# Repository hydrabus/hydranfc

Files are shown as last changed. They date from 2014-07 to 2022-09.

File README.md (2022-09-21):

HydraNFC Shield v1 and HydraNFC Antenna
========

HydraNFC hardware shield v1
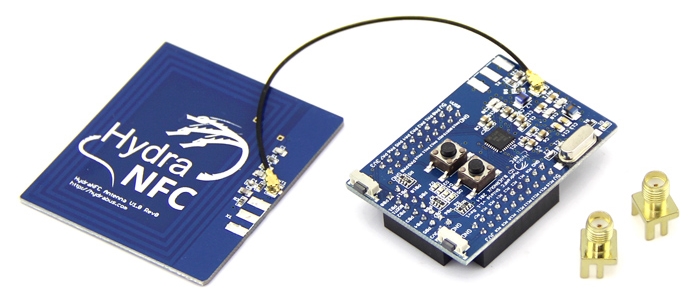
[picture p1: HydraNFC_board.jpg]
HydraNFC shield


The HydraNFC is an NFC shield hardware to sniff, read/write or emulate any 13.56MHz NFC tags for anyone interested in debugging/hacking/developing for NFC.
It has been designed to be used with HydraBus see https://github.com/hydrabus/hydrabus but can also be used with other MCU.

You can Buy HydraBus/HydraNFC Online: http://hydrabus.com/buy-online

Open source code firmware(For HydraBus), is available see
https://github.com/hydrabus/hydrafw

Wiki for HydraFW: https://github.com/hydrabus/hydrafw/wiki

Tutorial with HydraBus + HydraNFC  (using HydraFW v0.5 beta):
* Initialize GPIO & SPI to communicate with TRF7970A/HydraNFC
* Initialize & read ISO15693/Vicinity Tag
* Initialize & read ISO14443A/Mifare Tag
* Use TRF7970A commands (SLOS743K – August 2011 – revised April 2014)
* For more details see 
https://github.com/hydrabus/hydrafw/wiki/HydraFW-HydraNFC-v1-guide
https://github.com/hydrabus/hydrafw/wiki/HydraFW-HydraNFC-v1.x-TRF7970A-Tutorial

Tutorial to use HydraNFC and understand how work the NFC chipset (TRF7970A) with BusPirate or any other hardware with SPI:
* See http://bvernoux.blogspot.fr/2012/01/nfc-ti-trf7970a-breakout-board-v10-for.html

For more details on the hardware see also http://hydrabus.com/hydranfc-1-0-specifications

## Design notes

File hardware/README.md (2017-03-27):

HydraNFC Hardware
========

This directory contains HydraNFC Hardware: 
Schematic, Board for CadSoft Eagle 6.x (free version works too)
Documentations HydraNFC TRF7970A chipset Modes & Pin Out.

Licenses:
* HydraNFC_1_1_Rev1 and HydraNFC_Antenna_1_0_Rev0: Hardware license [CC BY-NC 4.0](https://creativecommons.org/licenses/by-nc/4.0/) (for commercial license contact info@hydrabus.com)

You can buy online HydraBus/HydraNFC: http://hydrabus.com/buy-online

For more details on the hardware see also http://hydrabus.com/hydranfc-1-0-specifications/

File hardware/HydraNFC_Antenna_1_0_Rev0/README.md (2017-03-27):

HydraNFC Antenna Schematic and Board CadSoft Eagle 6.x
========

This directory contains HydraNFC Antenna Schematic and Board for CadSoft Eagle 6.x

HydraNFC Antenna: Hardware license [CC BY-NC 4.0](https://creativecommons.org/licenses/by-nc/4.0/) (for commercial license contact info@hydrabus.com)

For more details on the hardware see also http://hydrabus.com/?page_id=30

HydraNFC Antenna PCB Top
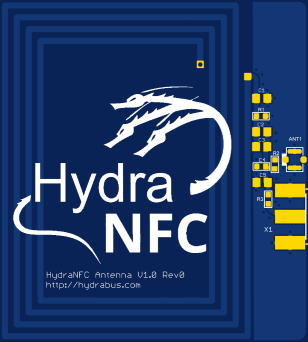
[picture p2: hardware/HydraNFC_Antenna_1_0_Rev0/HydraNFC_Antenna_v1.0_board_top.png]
HydraNFC Antenna PCB Top


HydraNFC Antenna PCB Bottom
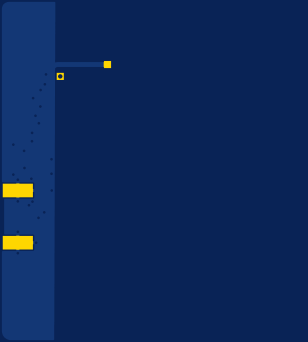
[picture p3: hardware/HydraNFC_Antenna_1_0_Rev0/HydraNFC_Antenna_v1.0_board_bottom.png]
HydraNFC Antenna PCB Bottom


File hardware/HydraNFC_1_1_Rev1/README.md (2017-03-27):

HydraNFC Shield Schematic and Board CadSoft Eagle 6.x
========

This directory contains HydraNFC shield Schematic and Board for CadSoft Eagle 6.x

HydraNFC shield: Hardware license [CC BY-NC 4.0](https://creativecommons.org/licenses/by-nc/4.0/) (for commercial license contact info@hydrabus.com)

For more details on the hardware see also http://hydrabus.com/?page_id=30

HydraNFC shield PCB Top
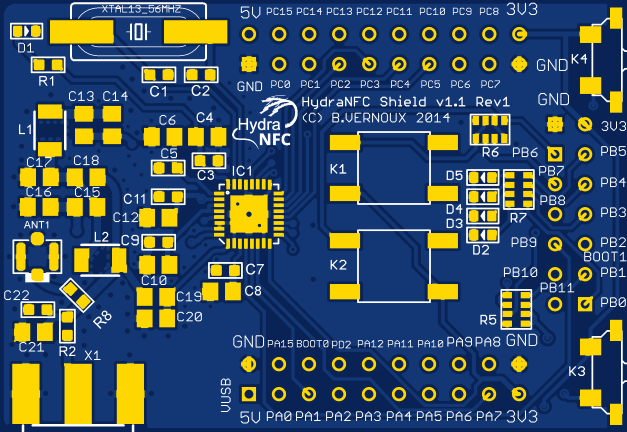
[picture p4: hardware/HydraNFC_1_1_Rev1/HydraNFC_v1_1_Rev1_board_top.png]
HydraNFC shield PCB Top


HydraNFC shield PCB Bottom
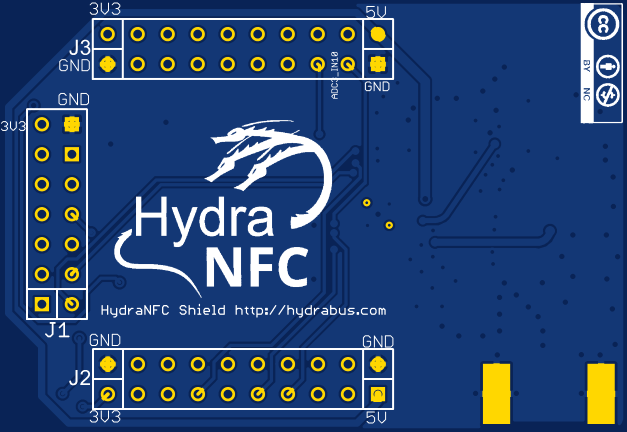
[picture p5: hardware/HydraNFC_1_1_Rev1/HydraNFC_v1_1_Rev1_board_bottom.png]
HydraNFC shield PCB Bottom


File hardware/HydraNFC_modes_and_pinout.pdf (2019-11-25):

Hydra NFC Pin | TRF7970A Pin | HydraBus Mode SPI With SS
PC0 | IO2 | +3V3 or TX SDM (Data En) out
PC1 | IO4_CS | SPI2 CS Master out
PC2 | IO6_MISO | SPI2 MISO Master or RX DM1 in
PC3 | IO7_MOSI | SPI2 MOSI Master out
PC4 | IO5 | TX SDM or RX DM1 CLK in
PC5 | IO3 | TX SDM out
PB1 | ASK_OOK | TX SDM or Direct Mode 0 out
PB10 | DATA_CLK | SPI2 CLK Master out
PB11 | EN (Chip En) | +3V3 out
PA1 | IRQ | IRQ Input in
PA2 | IO1 | +3V3 out
PA3 | IO0 | GND out
PA5 | SYS_CLK (Out) | SPI1 CLK Slave (sniffer) in
PA7 | MOD | SPI1 MOSI Slave (sniffer) in

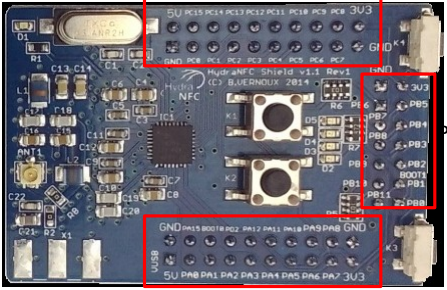
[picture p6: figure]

IO2: TX SDM Enable (TRF7970A Data Enable input)
IO3: TX SDM Data (TRF7970A Data Bit input)
IO5: TX SDM Clock or RX DM1 Clock (TRF7970A Data Clock output)
IO6: SPI MISO or RX DM1 Data (TRF7970A Data Bit output) or Direct Mode 0 (output) subcarrier signal (digitized RF envelope signal)
MOD: External data modulation input for Direct Mode 0 or 1
ASK/OOK: Selection between ASK and OOK modulation (0 = ASK, 1 = OOK) for Direct Mode 0 or 1. Can be configured as an output to provide the received analog signal output.
SYS_CLK: Options with 13.56-MHz crystal: Off, 3.39 MHz, 6.78 MHz, or 13.56 Mhz

RX DM1 = Receive Direct Mode 1 (TRF7970A receive), TX SDM = Transmit Special Direct Mode (TRF7970A transmit) TRF7970A Pin 16 is used to supply the I/O interface pins (I/O_0 to I/O_7), IRQ, SYS_CLK, and DATA_CLK pins of the reader.

PC

PA

PB

### HydraNFC Modes & Pinout

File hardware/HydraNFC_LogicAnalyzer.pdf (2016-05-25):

HydraNFC_LogicAnalyzer
LogicAnalyzer Chan | HydraNFC Pin | TRF7970A Pin | HydraBus Mode SPI With SS
0 PC3 | | IO7_MOSI | SPI2_MOSI Master out
1 PC2 | | IO6_MISO | SPI2_MISO Master or RX DM1 in
2 PB10 | | DATA_CLK | SPI2_CLK Master out
3 PC1 | | IO4_CS | SPI2_CS Master out
4 PA7 | | MOD | SPI1_MOSI Slave (sniffer) in
5 PA5 | | SYS_CLK (Out) | SPI1_CLK Slave (sniffer) in
6 PA1 | | IRQ | IRQ Input in
7 PC4 | | IO5 | TX SDM or RX DM1 CLK in
8 PC5 | | IO3 | TX SDM out
9 PB1 | | ASK_OOK | TX SDM or Direct Mode 0 out
10 PB11 | | EN (Chip En) | +3V3 out
11 PC0 | | IO2 | +3V3 or TX SDM (Data En) out
-PA2 | | IO1 | +3V3 out
-PA3 | | IO0 | GND out

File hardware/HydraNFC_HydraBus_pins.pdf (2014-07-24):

STM32F405RGT_pinNo

Pin N° | Pin Name | Pin Type | 5V pin Tolerant | Functions | AF0 | AF1 | AF2 | AF3 | AF4 | AF5 | AF6 | AF7 | AF8 | AF9 | AF10 | AF11 | AF12 | AF13 | AF14 | AF15 | Default Function HydraBus | HydraNFC TRF7970A
1 | VBAT | - | - | - | - | - | - | - | - | - | - | - | - | - | - | - | - | - | - | - | +3V3 | -
2 | PC13 | I/O | YES | EVENTOUT / RTC_AF1 | - | - | - | - | - | - | - | - | - | - | - | - | - | - | - | -
3 | PC14-OSC32_IN (PC14) | I/O | YES | EVENTOUT / OSC32_IN(4) | - | - | - | - | - | - | - | - | - | - | - | - | - | - | - | - | Optional RTC 32,768KHz
4 | PC15-OSC32_OUT (PC15) | I/O | YES | EVENTOUT / OSC32_OUT(4) | - | - | - | - | - | - | - | - | - | - | - | - | - | - | - | - | Optional RTC 32,768KHz
5 | PH0-OSC_IN (PH0) | I/O | YES | EVENTOUT / OSC_IN(4) | - | - | - | - | - | - | - | - | - | - | - | - | - | - | - | - | Quartz 8MHz | -
6 | PH1-OSC_OUT (PH1) | I/O | YES | EVENTOUT / OSC_OUT(4) | - | - | - | - | - | - | - | - | - | - | - | - | - | - | - | - | Quartz 8MHz | -
7 | NRST | I/O | - | - | - | - | - | - | - | - | - | - | - | - | - | - | - | - | - | - | Reset Button / SWD_DEBUG
8 | PC0 | I/O | YES | ADC123_IN10 | - | - | - | - | - | - | - | - | - | - | OTG_HS_ULPI_STP | - | - | - | - | EVENTOUT | | TRF7970A IO2 pin19 (Special Direct Mode TX Enable) (MCU Out set to "1" for SPI with SS)
9 | PC1 | I/O | YES | ADC123_IN11 | - | - | - | - | - | - | - | - | - | - | - | ETH_MDC | - | - | - | EVENTOUT | | TRF7970A IO4_SS pin21 (MCU SPI2 CS Master)
10 | PC2 | I/O | YES | ADC123_IN12 | - | - | - | - | - | SPI2_MISO | I2S2ext_SD | - | - | - | OTG_HS_ULPI_DIR | ETH _MII_TXD2 | - | - | - | EVENTOUT | | TRF7970A IO6_MISO SPI pin23 (MCU SPI2 MISO Master)
11 | PC3 | I/O | YES | ADC123_IN13 | - | - | - | - | - | SPI2_MOSI I2S2_SD | - | - | - | - | OTG_HS_ULPI_NXT | ETH _MII_TX_CLK | - | - | - | EVENTOUT | | TRF7970A IO7_MOSI SPI pin24 (MCU SPI2 MOSI Master)
12 | VSSA | - | - | - | - | - | - | - | - | - | - | - | - | - | - | - | - | - | - | - | - | -
13 | VDDA | - | - | - | - | - | - | - | - | - | - | - | - | - | - | - | - | - | - | - | - | -
14 | PA0-WKUP (PA0) | I/O | YES | ADC123_IN0 / WKUP(4) | - | TIM2_CH1 TIM2_ETR | TIM 5_CH1 | TIM8_ETR | - | - | - | USART2_CTS | UART4_TX | - | - | ETH_MII_CRS | - | - | - | EVENTOUT | UBTN (User Button 0) Can be disabled by removing Jumper JMP1 UBTN | HydraBus UBTN ABORT_BUTTON (MCU In)
15 | PA1 | I/O | YES | ADC123_IN1 | - | TIM2_CH2 | TIM5_CH2 | - | - | - | - | USART2_RTS | UART4_RX | - | - | ETH_MII _RX_CLK ETH_RMII__REF_ CLK | - | - | - | EVENTOUT | | TRF7970A IRQ pin13 (MCU Input IRQ_PIN)
16 | PA2 | I/O | YES | ADC123_IN2 | - | TIM2_CH3 | TIM5_CH3 | TIM9_CH1 | - | - | - | USART2_TX | - | - | - | ETH_MDIO | - | - | - | EVENTOUT | | TRF7970A IO1 pin18 (MCU Out set to "1" for SPI with SS)
17 | PA3 | I/O | YES | ADC123_IN3 | - | TIM2_CH4 | TIM5_CH4 | TIM9_CH2 | - | - | - | USART2_RX | - | - | OTG_HS_ULPI_D0 | ETH _MII_COL | - | - | - | EVENTOUT | | TRF7970A IO0 pin17 (MCU Out set to "0" for SPI with SS)
18 | VSS | - | - | - | - | - | - | - | - | - | - | - | - | - | - | - | - | - | - | - | - | -
19 | VDD | - | - | - | - | - | - | - | - | - | - | - | - | - | - | - | - | - | - | - | - | -
20 | PA4 | I/O | NO (3.3V) | ADC12_IN4 / DAC1_OUT | - | - | - | - | - | SPI1_NSS | SPI3_NSS I2S3_WS | USART2_CK | - | - | - | - | OTG_HS_SOF | DCMI_HSYNC | - | EVENTOUT | ULED (User LED 0) Can be disabled by removing Jumper JMP1 ULED
21 | PA5 | I/O | NO (3.3V) | ADC12_IN5 / DAC2_OUT | - | TIM2_CH1 TIM2_ETR | - | TIM8_CH1N | - | SPI1_SCK | - | - | - | - | OTG_HS_ULPI_CK | - | - | - | - | EVENTOUT | | TRF7970A SYS_CLK pin27 (MCU SPI1 SCK Slave) (Sniffer mode)
22 | PA6 | I/O | YES | ADC12_IN6 | - | TIM1_BKIN | TIM3_CH1 | TIM8_BKIN | - | SPI1_MISO | - | - | - | TIM13_CH1 | - | - | - | DCMI_PIXCK | - | EVENTOUT | | (MCU SPI1 MISO Not used/Not connected)
23 | PA7 | I/O | YES | ADC12_IN7 | - | TIM1_CH1N | TIM3_CH2 | TIM8_CH1N | - | SPI1_MOSI | - | - | - | TIM14_CH1 | - | ETH_MII _RX_DV ETH_RMII _CRS_DV | - | - | - | EVENTOUT | | TRF7970A MOD pin14 (IN/OUT) (MCU SPI1 MOSI Slave) (Sniffer mode)
24 | PC4 | I/O | YES | ADC12_IN14 | - | - | - | - | - | - | - | - | - | - | - | ETH_MII_RXD0 ETH_RMII_RXD0 | - | - | - | EVENTOUT | | TRF7970A IO5 pin22 (not used for SPI mode / Data clock OUT) (MCU Out set to 0 default)
25 | PC5 | I/O | YES | ADC12_IN15 | - | - | - | - | - | - | - | - | - | - | - | ETH _MII_RXD1 ETH _RMII_RXD1 | - | - | - | EVENTOUT | | TRF7970A IO3 pin20 (Special Direct Mode TX_Data) (not used for SPI mode) (MCU Out set to 0 default / NA in SPI with SS)
26 | PB0 | I/O | YES | ADC12_IN8 | - | TIM1_CH2N | TIM3_CH3 | TIM8_CH2N | - | - | - | - | - | - | OTG_HS_ULPI_D1 | ETH _MII_RXD2 | - | - | - | EVENTOUT | | LED D2 or TST_PIN (TST_ON/TST_OFF) MCU Out fastest for oscilloscope timing checks
27 | PB1 | I/O | YES | ADC12_IN9 | - | TIM1_CH3N | TIM3_CH4 | TIM8_CH3N | - | - | - | - | - | - | OTG_HS_ULPI_D2 | ETH _MII_RXD3 | - | - | - | EVENTOUT | | TRF7970A ASK_OOK pin12 (IN/OUT)
28 | PB2-BOOT1 (PB2) | I/O | YES | | - | - | - | - | - | - | - | - | - | - | - | - | - | - | - | EVENTOUT
29 | PB10 | I/O | YES | | - | TIM2_CH3 | - | - | I2C2_SCL | SPI2_SCK I2S2_CK | - | USART3_TX | - | - | OTG_HS_ULPI_D3 | ETH_ MII_RX_ER | - | - | - | EVENTOUT | | TRF7970A DATA_CLK pin26 (MCU SPI2 SCK Master)
30 | PB11 | I/O | YES | | - | TIM2_CH4 | - | - | I2C2_SDA | - | - | USART3_RX | - | - | OTG_HS_ULPI_D4 | ETH _MII_TX_EN ETH _RMII_TX_EN | - | - | - | EVENTOUT | | TRF7970A EN (Chip Enable) pin28 (MCU Out set to "1"to enable TRF7970A)
31 | VCAP_1 | - | - | - | - | - | - | - | - | - | - | - | - | - | - | - | - | - | - | - | - | -
32 | VDD | - | - | - | - | - | - | - | - | - | - | - | - | - | - | - | - | - | - | - | - | -
33 | PB12 | I/O | YES | | - | TIM1_BKIN | - | - | I2C2_SMBA | SPI2_NSS I2S2_WS | - | USART3_CK | - | CAN2_RX | OTG_HS_ULPI_D5 | ETH _MII_TXD0 ETH _RMII_TXD0 | OTG_HS_ID | - | - | EVENTOUT | USB ID (USB1 connector) | -
34 | PB13 | I/O | YES | OTG_HS_VBUS | - | TIM1_CH1N | - | - | - | SPI2_SCK I2S2_CK | - | USART3_CTS | - | CAN2_TX | OTG_HS_ULPI_D6 | ETH _MII_TXD1 ETH _RMII_TXD1 | - | - | - | EVENTOUT | Supply VUSB (USB1 connector) | -
35 | PB14 | I/O | YES | | - | TIM1_CH2N | - | TIM8_CH2N | - | SPI2_MISO | I2S2ext_SD | USART3_RTS | - | TIM12_CH1 | - | - | OTG_HS_DM | - | - | EVENTOUT | USB D-(USB1 connector) | -
36 | PB15 | I/O | YES | | RTC_50Hz | TIM1_CH3N | - | TIM8_CH3N | - | SPI2_MOSI I2S2_SD | - | - | - | TIM12_CH2 | - | - | OTG_HS_DP | - | - | EVENTOUT | USB D+ (USB1 connector) | -
37 | PC6 | I/O | YES | | - | - | TIM3_CH1 | TIM8_CH1 | - | I2S2_MCK | - | - | USART6_TX | - | - | - | SDIO_D6 | DCMI_D0 | - | EVENTOUT
38 | PC7 | I/O | YES | | - | - | TIM3_CH2 | TIM8_CH2 | | | I2S3_MCK | | USART6_RX | | | | SDIO_D7 | DCMI_D1 | | EVENTOUT
39 | PC8 | I/O | YES | | - | - | TIM3_CH3 | TIM8_CH3 | | | | | USART6_CK | | | | SDIO_D0 | DCMI_D2 | | EVENTOUT | MicroSD Card SD 4bits SDIO_D0 | -
40 | PC9 | I/O | YES | | MCO2 | - | TIM3_CH4 | TIM8_CH4 | I2C3_SDA | I2S_CKIN | | | | | | | SDIO_D1 | DCMI_D3 | | EVENTOUT | MicroSD Card SD 4bits SDIO_D1 | -
41 | PA8 | I/O | YES | | MCO1 | TIM1_CH1 | - | - | I2C3_SCL | - | - | USART1_CK | - | - | OTG_FS_SOF | - | - | - | - | EVENTOUT
42 | PA9 | I/O | YES | OTG_FS_VBUS | - | TIM1_CH2 | - | - | I2C3_SMBA | - | - | USART1_TX | - | - | | - | - | DCMI_D0 | - | EVENTOUT
43 | PA10 | I/O | YES | | - | TIM1_CH3 | - | - | | - | - | USART1_RX | - | - | OTG_FS_ID | - | - | DCMI_D1 | - | EVENTOUT
44 | PA11 | I/O | YES | | - | TIM1_CH4 | - | - | | - | - | USART1_CTS | - | CAN1_RX | OTG_FS_DM | - | - | - | - | EVENTOUT | USB D-(USB0 connector) | -
45 | PA12 | I/O | YES | | - | TIM1_ETR | - | - | - | - | - | USART1_RTS | - | CAN1_TX | OTG_FS_DP | - | - | - | - | EVENTOUT | USB D+ (USB0 connector) | -
46 | PA13 (JTMS-SWDIO) | I/O | YES | | JTMS-SWDIO | - | - | - | - | - | - | - | - | - | - | - | - | - | - | EVENTOUT | SWDIO | -
47 | VCAP_2 | - | - | - | - | - | - | - | - | - | - | - | - | - | - | - | - | - | - | - | - | -
48 | VDD | - | - | - | - | - | - | - | - | - | - | - | - | - | - | - | - | - | - | - | - | -
49 | PA14 (JTCK-SWCLK) | I/O | YES | | TCK-SWCLK | - | - | - | - | - | - | - | - | - | - | - | - | - | - | EVENTOUT | SWCLK | -
50 | PA15 (JTDI) | I/O | YES | | JTDI | TIM 2_CH1 TIM 2_ETR | - | - | - | SPI1_NSS | SPI3_NSS/ I2S3S_WS | - | - | - | - | - | - | - | - | EVENTOUT | | (MCU SPI1 NSS Slave) (Sniffer mode)
51 | PC10 | I/O | YES | | - | - | - | - | - | - | SPI3_SCK/ I2S3S_CK | USART3_TX/ | UART4_TX | - | - | - | SDIO_D2 | DCMI_D8 | - | EVENTOUT | MicroSD Card SD 4bits SDIO_D2 | -
52 | PC11 | I/O | YES | | - | - | - | - | - | I2S3ext_SD | SPI3_MISO/ | USART3_RX | UART4_RX | - | - | - | SDIO_D3 | DCMI_D4 | - | EVENTOUT | MicroSD Card SD 4bits SDIO_D3 | -
53 | PC12 | I/O | YES | | - | - | - | - | - | - | SPI3_MOSI I2S3_SD | USART3_CK | UART5_TX | - | - | - | SDIO_CK | DCMI_D9 | - | EVENTOUT | MicroSD Card SD 4bits SDIO_CK | -
54 | PD2 | I/O | YES | | - | - | TIM3_ETR | - | - | - | - | - | UART5_RX | - | - | - | SDIO_CMD | DCMI_D11 | - | EVENTOUT | MicroSD Card SD 4bits SDIO_CMD | -
55 | PB3 (JTDO/ TRACESWO) | I/O | YES | | JTDO/ TRACESWO | TIM2_CH2 | - | - | - | SPI1_SCK | SPI3_SCK I2S3_CK | - | - | - | - | - | - | - | - | EVENTOUT | | LED D3 (MCU Out)
56 | PB4 (NJTRST) | I/O | YES | | NJTRST | - | TIM3_CH1 | - | - | SPI1_MISO | SPI3_MISO | I2S3ext_SD | - | - | - | - | - | - | - | EVENTOUT | | LED D4 (MCU Out)
57 | PB5 | I/O | YES | | - | - | TIM3_CH2 | - | I2C1_SMBA | SPI1_MOSI | SPI3_MOSI I2S3_SD | - | - | CAN2_RX | OTG_HS_ULPI_D7 | ETH _PPS_OUT | - | DCMI_D10 | - | EVENTOUT | | LED D5 (MCU Out)
58 | PB6 | I/O | YES | | - | - | TIM4_CH1 | - | I2C1_SCL | - | - | USART1_TX | - | CAN2_TX | - | - | - | DCMI_D5 | - | EVENTOUT | | BUTTON K2 (MCU In)
59 | PB7 | I/O | YES | | - | - | TIM4_CH2 | - | I2C1_SDA | - | - | USART1_RX | - | - | - | - | FSMC_NL | DCMI_VSYNC | - | EVENTOUT | | BUTTON K1 (MCU In)
60 | BOOT0 | I | - | - | - | - | - | - | - | - | - | - | - | - | - | - | - | - | - | - | Default Boot from Flash (pull-down resistor 2.2Kohms) | -
61 | PB8 | I/O | YES | | - | - | TIM4_CH3 | TIM10_CH1 | I2C1_SCL | - | - | - | - | CAN1_RX | - | ETH _MII_TXD3 | SDIO_D4 | DCMI_D6 | - | EVENTOUT | | BUTTON K3 (MCU In)
62 | PB9 | I/O | YES | | - | - | TIM4_CH4 | TIM11_CH1 | I2C1_SDA | SPI2_NSS I2S2_WS | - | - | - | CAN1_TX | - | - | SDIO_D5 | DCMI_D7 | - | EVENTOUT | | BUTTON K4 (MCU In)
63 | VSS | - | - | - | - | - | - | - | - | - | - | - | - | - | - | - | - | - | - | - | - | -
64 | VDD | - | - | - | - | - | - | - | - | - | - | - | - | - | - | - | - | - | - | - | - | -

Pin 3.3V Only !! Not 5V tolerant
Default Function HydraBus
HydraBus Conf HydraNFC TRF7970A

STM32F405RGT_TRF7970A_IO

Pin N° | Pin Name | Pin Type | 5V pin Tolerant | Functions | AF0 | AF1 | AF2 | AF3 | AF4 | AF5 | AF6 | AF7 | AF8 | AF9 | AF10 | AF11 | AF12 | AF13 | AF14 | AF15 | Default Function HydraBus | HydraNFC TRF7970A
1 | VBAT | - | - | - | - | - | - | - | - | - | - | - | - | - | - | - | - | - | - | - | +3V3 | -
12 | VSSA | - | - | - | - | - | - | - | - | - | - | - | - | - | - | - | - | - | - | - | - | -
13 | VDDA | - | - | - | - | - | - | - | - | - | - | - | - | - | - | - | - | - | - | - | - | -
18 | VSS | - | - | - | - | - | - | - | - | - | - | - | - | - | - | - | - | - | - | - | - | -
19 | VDD | - | - | - | - | - | - | - | - | - | - | - | - | - | - | - | - | - | - | - | - | -
31 | VCAP_1 | - | - | - | - | - | - | - | - | - | - | - | - | - | - | - | - | - | - | - | - | -
32 | VDD | - | - | - | - | - | - | - | - | - | - | - | - | - | - | - | - | - | - | - | - | -
33 | PB12 | I/O | YES | | - | TIM1_BKIN | - | - | I2C2_SMBA | SPI2_NSS I2S2_WS | - | USART3_CK | - | CAN2_RX | OTG_HS_ULPI_D5 | ETH _MII_TXD0 ETH _RMII_TXD0 | OTG_HS_ID | - | - | EVENTOUT | USB ID (USB1 connector) | -
34 | PB13 | I/O | YES | OTG_HS_VBUS | - | TIM1_CH1N | - | - | - | SPI2_SCK I2S2_CK | - | USART3_CTS | - | CAN2_TX | OTG_HS_ULPI_D6 | ETH _MII_TXD1 ETH _RMII_TXD1 | - | - | - | EVENTOUT | Supply VUSB (USB1 connector) | -
35 | PB14 | I/O | YES | | - | TIM1_CH2N | - | TIM8_CH2N | - | SPI2_MISO | I2S2ext_SD | USART3_RTS | - | TIM12_CH1 | - | - | OTG_HS_DM | - | - | EVENTOUT | USB D-(USB1 connector) | -
36 | PB15 | I/O | YES | | RTC_50Hz | TIM1_CH3N | - | TIM8_CH3N | - | SPI2_MOSI I2S2_SD | - | - | - | TIM12_CH2 | - | - | OTG_HS_DP | - | - | EVENTOUT | USB D+ (USB1 connector) | -
39 | PC8 | I/O | YES | | - | - | TIM3_CH3 | TIM8_CH3 | | | | | USART6_CK | | | | SDIO_D0 | DCMI_D2 | | EVENTOUT | MicroSD Card SD 4bits SDIO_D0 | -
40 | PC9 | I/O | YES | | MCO2 | - | TIM3_CH4 | TIM8_CH4 | I2C3_SDA | I2S_CKIN | | | | | | | SDIO_D1 | DCMI_D3 | | EVENTOUT | MicroSD Card SD 4bits SDIO_D1 | -
44 | PA11 | I/O | YES | | - | TIM1_CH4 | - | - | | - | - | USART1_CTS | - | CAN1_RX | OTG_FS_DM | - | - | - | - | EVENTOUT | USB D-(USB0 connector) | -
45 | PA12 | I/O | YES | | - | TIM1_ETR | - | - | - | - | - | USART1_RTS | - | CAN1_TX | OTG_FS_DP | - | - | - | - | EVENTOUT | USB D+ (USB0 connector) | -
46 | PA13 (JTMS-SWDIO) | I/O | YES | | JTMS-SWDIO | - | - | - | - | - | - | - | - | - | - | - | - | - | - | EVENTOUT | SWDIO | -
47 | VCAP_2 | - | - | - | - | - | - | - | - | - | - | - | - | - | - | - | - | - | - | - | - | -
48 | VDD | - | - | - | - | - | - | - | - | - | - | - | - | - | - | - | - | - | - | - | - | -
49 | PA14 (JTCK-SWCLK) | I/O | YES | | TCK-SWCLK | - | - | - | - | - | - | - | - | - | - | - | - | - | - | EVENTOUT | SWCLK | -
51 | PC10 | I/O | YES | | - | - | - | - | - | - | SPI3_SCK/ I2S3S_CK | USART3_TX/ | UART4_TX | - | - | - | SDIO_D2 | DCMI_D8 | - | EVENTOUT | MicroSD Card SD 4bits SDIO_D2 | -
52 | PC11 | I/O | YES | | - | - | - | - | - | I2S3ext_SD | SPI3_MISO/ | USART3_RX | UART4_RX | - | - | - | SDIO_D3 | DCMI_D4 | - | EVENTOUT | MicroSD Card SD 4bits SDIO_D3 | -
53 | PC12 | I/O | YES | | - | - | - | - | - | - | SPI3_MOSI I2S3_SD | USART3_CK | UART5_TX | - | - | - | SDIO_CK | DCMI_D9 | - | EVENTOUT | MicroSD Card SD 4bits SDIO_CK | -
54 | PD2 | I/O | YES | | - | - | TIM3_ETR | - | - | - | - | - | UART5_RX | - | - | - | SDIO_CMD | DCMI_D11 | - | EVENTOUT | MicroSD Card SD 4bits SDIO_CMD | -
60 | BOOT0 | I | - | - | - | - | - | - | - | - | - | - | - | - | - | - | - | - | - | - | Default Boot from Flash (pull-down resistor 2.2Kohms) | -
63 | VSS | - | - | - | - | - | - | - | - | - | - | - | - | - | - | - | - | - | - | - | - | -
64 | VDD | - | - | - | - | - | - | - | - | - | - | - | - | - | - | - | - | - | - | - | - | -
59 | PB7 | I/O | YES | | - | - | TIM4_CH2 | - | I2C1_SDA | - | - | USART1_RX | - | - | - | - | FSMC_NL | DCMI_VSYNC | - | EVENTOUT | | BUTTON K1 (MCU In)
58 | PB6 | I/O | YES | | - | - | TIM4_CH1 | - | I2C1_SCL | - | - | USART1_TX | - | CAN2_TX | - | - | - | DCMI_D5 | - | EVENTOUT | | BUTTON K2 (MCU In)
61 | PB8 | I/O | YES | | - | - | TIM4_CH3 | TIM10_CH1 | I2C1_SCL | - | - | - | - | CAN1_RX | - | ETH _MII_TXD3 | SDIO_D4 | DCMI_D6 | - | EVENTOUT | | BUTTON K3 (MCU In)
62 | PB9 | I/O | YES | | - | - | TIM4_CH4 | TIM11_CH1 | I2C1_SDA | SPI2_NSS I2S2_WS | - | - | - | CAN1_TX | - | - | SDIO_D5 | DCMI_D7 | - | EVENTOUT | | BUTTON K4 (MCU In)
14 | PA0-WKUP (PA0) | I/O | YES | ADC123_IN0 / WKUP(4) | - | TIM2_CH1 TIM2_ETR | TIM 5_CH1 | TIM8_ETR | - | - | - | USART2_CTS | UART4_TX | - | - | ETH_MII_CRS | - | - | - | EVENTOUT | UBTN (User Button 0) Can be disabled by removing Jumper JMP1 UBTN | HydraBus UBTN ABORT_BUTTON (MCU In)
26 | PB0 | I/O | YES | ADC12_IN8 | - | TIM1_CH2N | TIM3_CH3 | TIM8_CH2N | - | - | - | - | - | - | OTG_HS_ULPI_D1 | ETH _MII_RXD2 | - | - | - | EVENTOUT | | LED D2 or TST_PIN (TST_ON/TST_OFF) MCU Out fastest for oscilloscope timing checks
55 | PB3 (JTDO/ TRACESWO) | I/O | YES | | JTDO/ TRACESWO | TIM2_CH2 | - | - | - | SPI1_SCK | SPI3_SCK I2S3_CK | - | - | - | - | - | - | - | - | EVENTOUT | | LED D3 (MCU Out)
56 | PB4 (NJTRST) | I/O | YES | | NJTRST | - | TIM3_CH1 | - | - | SPI1_MISO | SPI3_MISO | I2S3ext_SD | - | - | - | - | - | - | - | EVENTOUT | | LED D4 (MCU Out)
57 | PB5 | I/O | YES | | - | - | TIM3_CH2 | - | I2C1_SMBA | SPI1_MOSI | SPI3_MOSI I2S3_SD | - | - | CAN2_RX | OTG_HS_ULPI_D7 | ETH _PPS_OUT | - | DCMI_D10 | - | EVENTOUT | | LED D5 (MCU Out)
27 | PB1 | I/O | YES | ADC12_IN9 | - | TIM1_CH3N | TIM3_CH4 | TIM8_CH3N | - | - | - | - | - | - | OTG_HS_ULPI_D2 | ETH _MII_RXD3 | - | - | - | EVENTOUT | | TRF7970A ASK_OOK pin12 (IN/OUT)
15 | PA1 | I/O | YES | ADC123_IN1 | - | TIM2_CH2 | TIM5_CH2 | - | - | - | - | USART2_RTS | UART4_RX | - | - | ETH_MII _RX_CLK ETH_RMII__REF_ CLK | - | - | - | EVENTOUT | | TRF7970A IRQ pin13 (MCU Input IRQ_PIN)
22 | PA6 | I/O | YES | ADC12_IN6 | - | TIM1_BKIN | TIM3_CH1 | TIM8_BKIN | - | SPI1_MISO | - | - | - | TIM13_CH1 | - | - | - | DCMI_PIXCK | - | EVENTOUT | | (MCU SPI1 MISO Not used/Not connected)
23 | PA7 | I/O | YES | ADC12_IN7 | - | TIM1_CH1N | TIM3_CH2 | TIM8_CH1N | - | SPI1_MOSI | - | - | - | TIM14_CH1 | - | ETH_MII _RX_DV ETH_RMII _CRS_DV | - | - | - | EVENTOUT | | TRF7970A MOD pin14 (IN/OUT) (MCU SPI1 MOSI Slave) (Sniffer mode)
21 | PA5 | I/O | NO (3.3V) | ADC12_IN5 / DAC2_OUT | - | TIM2_CH1 TIM2_ETR | - | TIM8_CH1N | - | SPI1_SCK | - | - | - | - | OTG_HS_ULPI_CK | - | - | - | - | EVENTOUT | | TRF7970A SYS_CLK pin27 (MCU SPI1 SCK Slave) (Sniffer mode)
50 | PA15 (JTDI) | I/O | YES | | JTDI | TIM 2_CH1 TIM 2_ETR | - | - | - | SPI1_NSS | SPI3_NSS/ I2S3S_WS | - | - | - | - | - | - | - | - | EVENTOUT | | (MCU SPI1 NSS Slave) (Sniffer mode)
30 | PB11 | I/O | YES | | - | TIM2_CH4 | - | - | I2C2_SDA | - | - | USART3_RX | - | - | OTG_HS_ULPI_D4 | ETH _MII_TX_EN ETH _RMII_TX_EN | - | - | - | EVENTOUT | | TRF7970A EN (Chip Enable) pin28 (MCU Out set to "1"to enable TRF7970A)
17 | PA3 | I/O | YES | ADC123_IN3 | - | TIM2_CH4 | TIM5_CH4 | TIM9_CH2 | - | - | - | USART2_RX | - | - | OTG_HS_ULPI_D0 | ETH _MII_COL | - | - | - | EVENTOUT | | TRF7970A IO0 pin17 (MCU Out set to "0" for SPI with SS)
16 | PA2 | I/O | YES | ADC123_IN2 | - | TIM2_CH3 | TIM5_CH3 | TIM9_CH1 | - | - | - | USART2_TX | - | - | - | ETH_MDIO | - | - | - | EVENTOUT | | TRF7970A IO1 pin18 (MCU Out set to "1" for SPI with SS)
8 | PC0 | I/O | YES | ADC123_IN10 | - | - | - | - | - | - | - | - | - | - | OTG_HS_ULPI_STP | - | - | - | - | EVENTOUT | | TRF7970A IO2 pin19 (Special Direct Mode TX Enable) (MCU Out set to "1" for SPI with SS)
25 | PC5 | I/O | YES | ADC12_IN15 | - | - | - | - | - | - | - | - | - | - | - | ETH _MII_RXD1 ETH _RMII_RXD1 | - | - | - | EVENTOUT | | TRF7970A IO3 pin20 (Special Direct Mode TX_Data) (not used for SPI mode) (MCU Out set to 0 default / NA in SPI with SS)
9 | PC1 | I/O | YES | ADC123_IN11 | - | - | - | - | - | - | - | - | - | - | - | ETH_MDC | - | - | - | EVENTOUT | | TRF7970A IO4_SS pin21 (MCU SPI2 CS Master)
24 | PC4 | I/O | YES | ADC12_IN14 | - | - | - | - | - | - | - | - | - | - | - | ETH_MII_RXD0 ETH_RMII_RXD0 | - | - | - | EVENTOUT | | TRF7970A IO5 pin22 (not used for SPI mode / Data clock OUT) (MCU Out set to 0 default)
10 | PC2 | I/O | YES | ADC123_IN12 | - | - | - | - | - | SPI2_MISO | I2S2ext_SD | - | - | - | OTG_HS_ULPI_DIR | ETH _MII_TXD2 | - | - | - | EVENTOUT | | TRF7970A IO6_MISO SPI pin23 (MCU SPI2 MISO Master)
11 | PC3 | I/O | YES | ADC123_IN13 | - | - | - | - | - | SPI2_MOSI I2S2_SD | - | - | - | - | OTG_HS_ULPI_NXT | ETH _MII_TX_CLK | - | - | - | EVENTOUT | | TRF7970A IO7_MOSI SPI pin24 (MCU SPI2 MOSI Master)
29 | PB10 | I/O | YES | | - | TIM2_CH3 | - | - | I2C2_SCL | SPI2_SCK I2S2_CK | - | USART3_TX | - | - | OTG_HS_ULPI_D3 | ETH_ MII_RX_ER | - | - | - | EVENTOUT | | TRF7970A DATA_CLK pin26 (MCU SPI2 SCK Master)
2 | PC13 | I/O | YES | EVENTOUT / RTC_AF1 | - | - | - | - | - | - | - | - | - | - | - | - | - | - | - | -
3 | PC14-OSC32_IN (PC14) | I/O | YES | EVENTOUT / OSC32_IN(4) | - | - | - | - | - | - | - | - | - | - | - | - | - | - | - | - | Optional RTC 32,768KHz
4 | PC15-OSC32_OUT (PC15) | I/O | YES | EVENTOUT / OSC32_OUT(4) | - | - | - | - | - | - | - | - | - | - | - | - | - | - | - | - | Optional RTC 32,768KHz
5 | PH0-OSC_IN (PH0) | I/O | YES | EVENTOUT / OSC_IN(4) | - | - | - | - | - | - | - | - | - | - | - | - | - | - | - | - | Quartz 8MHz | -
6 | PH1-OSC_OUT (PH1) | I/O | YES | EVENTOUT / OSC_OUT(4) | - | - | - | - | - | - | - | - | - | - | - | - | - | - | - | - | Quartz 8MHz | -
7 | NRST | I/O | - | - | - | - | - | - | - | - | - | - | - | - | - | - | - | - | - | - | Reset Button / SWD_DEBUG
20 | PA4 | I/O | NO (3.3V) | ADC12_IN4 / DAC1_OUT | - | - | - | - | - | SPI1_NSS | SPI3_NSS I2S3_WS | USART2_CK | - | - | - | - | OTG_HS_SOF | DCMI_HSYNC | - | EVENTOUT | ULED (User LED 0) Can be disabled by removing Jumper JMP1 ULED
28 | PB2-BOOT1 (PB2) | I/O | YES | | - | - | - | - | - | - | - | - | - | - | - | - | - | - | - | EVENTOUT
37 | PC6 | I/O | YES | | - | - | TIM3_CH1 | TIM8_CH1 | - | I2S2_MCK | - | - | USART6_TX | - | - | - | SDIO_D6 | DCMI_D0 | - | EVENTOUT
38 | PC7 | I/O | YES | | - | - | TIM3_CH2 | TIM8_CH2 | | | I2S3_MCK | | USART6_RX | | | | SDIO_D7 | DCMI_D1 | | EVENTOUT
41 | PA8 | I/O | YES | | MCO1 | TIM1_CH1 | - | - | I2C3_SCL | - | - | USART1_CK | - | - | OTG_FS_SOF | - | - | - | - | EVENTOUT
42 | PA9 | I/O | YES | OTG_FS_VBUS | - | TIM1_CH2 | - | - | I2C3_SMBA | - | - | USART1_TX | - | - | | - | - | DCMI_D0 | - | EVENTOUT
43 | PA10 | I/O | YES | | - | TIM1_CH3 | - | - | | - | - | USART1_RX | - | - | OTG_FS_ID | - | - | DCMI_D1 | - | EVENTOUT

Pin 3.3V Only !! Not 5V tolerant
Default Function HydraBus
HydraBus Conf HydraNFC TRF7970A

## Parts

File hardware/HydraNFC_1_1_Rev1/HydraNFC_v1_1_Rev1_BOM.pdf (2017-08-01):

HydraNFC_V1_1_Rev1_BOM

ITEM | QTY | REF DESIGN | DESCRIPTION | Mfg | Mfg Part Number | OPL | Mouser PN | Digi-Key PN
| | CONN HEADER FMAL 14PS .1" DL TIN (including GND+3V3) 2x7 pin header 2.54mm lengthen female. CONN HEADER FMAL 20PS .1" DL TIN x2 (including 3V3+GND and 5V+GND): 2x10 pin header 2.54mm lengthen female.
5 | 2 | K3 & K4 | BUTTON-2P-REINFORCE-3100060P1 4P-SMD-7.0X3.5X3.5H-90D | | | 3100060P1 | - | -
6 | 3 | C1 & C2 & C22 | Capacitor, 27pF, 0603 | | | 0100410P1 | - | -
7 | 5 | C3 & C5 & C7 & C9 & C11 | Capacitor, 100nF 0603 | | | 0100020P1 | - | -
8 | 5 | C4 & C6 & C8 & C10 & C12 | Capacitor, 2.2uF, Ceramic, +/-10%, X7R, (10V), (0805) | Kemet | C0805C225K8RACTU | - | 80-C0805C225K8R | 399-3125-1-ND
9 | 2 | C13 & C14 | Capacitor, 1500pF, (1,5nF) Ceramic +/-10%, X7R, (50V) 0805 | AVX Corporation | 08055C152KAT2A | - | 581-08055C152K | 478-1373-1-ND
10 | 2 | C15 & C16 | Capacitor, 1200pF, +/-10%, Ceramic X7R, (50V), (0805) | AVX Corporation | 08055C122KAT2A | - | 581-08055C122K | 478-1372-1-ND
11 | 2 | C17 & C20 | Capacitor, 680pF, +/- 5% 680pF 25volts X7R 5% 0805 | Vishay / Vitramon | VJ0805Y681JXXCW1BC | - | 77-VJ0805Y681JXXCBC | 445-7503-1-ND
12 | 1 | C19 | Capacitor, 220pF, +/- 5%, Ceramic 50V 5% NP0 0805 | AVX Corporation | 08055A221JAT2A | - | 581-08055A221J | 478-1320-1-ND
13 | 1 | C21 | Capacitor, 100pF, +/- 5%, Ceramic 16V 5% NP0 0805 | AVX Corporation | 0805YA101JAT2A | - | 581-0805YA101JAT2A | 445-1329-1-ND
14 | 1 | C18 | Capacitor, 10pF, +/- 5%, Ceramic 50V 5% NP0 0805 | AVX Corporation | 08055A100JAT2A | - | 581-08055A100J | 478-1304-1-ND
15 | 1 | R1 | Resistor 4.7K 0603 | | | 0010030P1 | - | -
16 | 2 | R2 & R8 | Resistor 0 Ohm 0603 | | | 0010070P1 | - | -
17 | 2 | R5 & R6 | SMD RES ARRAY 10K OHM 4 RES 1206 | | | 0040070P1 | - | -
18 | 1 | R7 | SMD RES ARRAY 4.7K OHM 4 RES 1206 | | | 0040040P1 | - | -
19 | 1 | D1 | Power LED Blue Clear 0603 SMD | | | 0330060P1 | - | -
20 | 3 | D2 & D3 & D4 | LED Clear Green 0603 SMD | | | 0330010P1 | - | -
21 | 1 | D5 | LED Red Diffused 0603 SMD | | | 0330020P1 | - | -
22 | 1 | IC1 | IC RFID/NFC 13.56MHz 32QFN | Texas Instruments | TRF7970ARHBT | - | 595-TRF7970ARHBT | 296-29476-1-ND
23 | 1 | L1 | Inductor, 150nH +-5%, (Q = 45), (Idc = 580 mA), (1008) | Abracon | AISC-1008-R15J-T | - | 815-AISC-1008-R15J | 535-10541-1-ND
24 | 1 | L2 | Inductor, 330nH +-5%, (Q = 45), (Idc = 450 mA), (1008) | Abracon | AISC-1008-R33J-T | - | 815-AISC-1008-R33J | 535-10545-1-ND
25 | 1 | ANT1 | U-FL-CONNECTOR | | | 3450020P1
26 | - | X1 | SMA 50 Ohm End Launch Jack Receptacle - Round Contact | JOHNSON COMPONENTS | 142-0701-801 | - | 530-142-0701-801 | J502-ND
1 | 1 | XTAL13_56MHZ | Xtal, 13.56 MHz, Ftol +-10ppm, CRYSTAL 13.560 MHZ 18pF HC49/US SMD | TXC CORPORATION | 9C-13.560MEEJ-T | - | 717-9C-13.560MEEJ-T | 887-1270-1-ND
2 | 1 | J1 | | Sullins Connector Solutions | PPTC072LFBN-RC | - | - | S7075-ND
3 | 2 | J2 & J3 | | Sullins Connector Solutions | PPTC102LFBN-RC | - | - | S7078-ND
4 | 2 | K1 & K2 | BUTTON-4P-3100010P1 4P-SMD-6.0X6.0X5.0H | | | 3100010P1 | - | -

YELLOW = DNP = Optional Do Not Populate, add it with board as kit
BLUE = Seeed Studio Open Part Library (OPL) http://www.seeedstudio.com/wiki/Open_parts_library

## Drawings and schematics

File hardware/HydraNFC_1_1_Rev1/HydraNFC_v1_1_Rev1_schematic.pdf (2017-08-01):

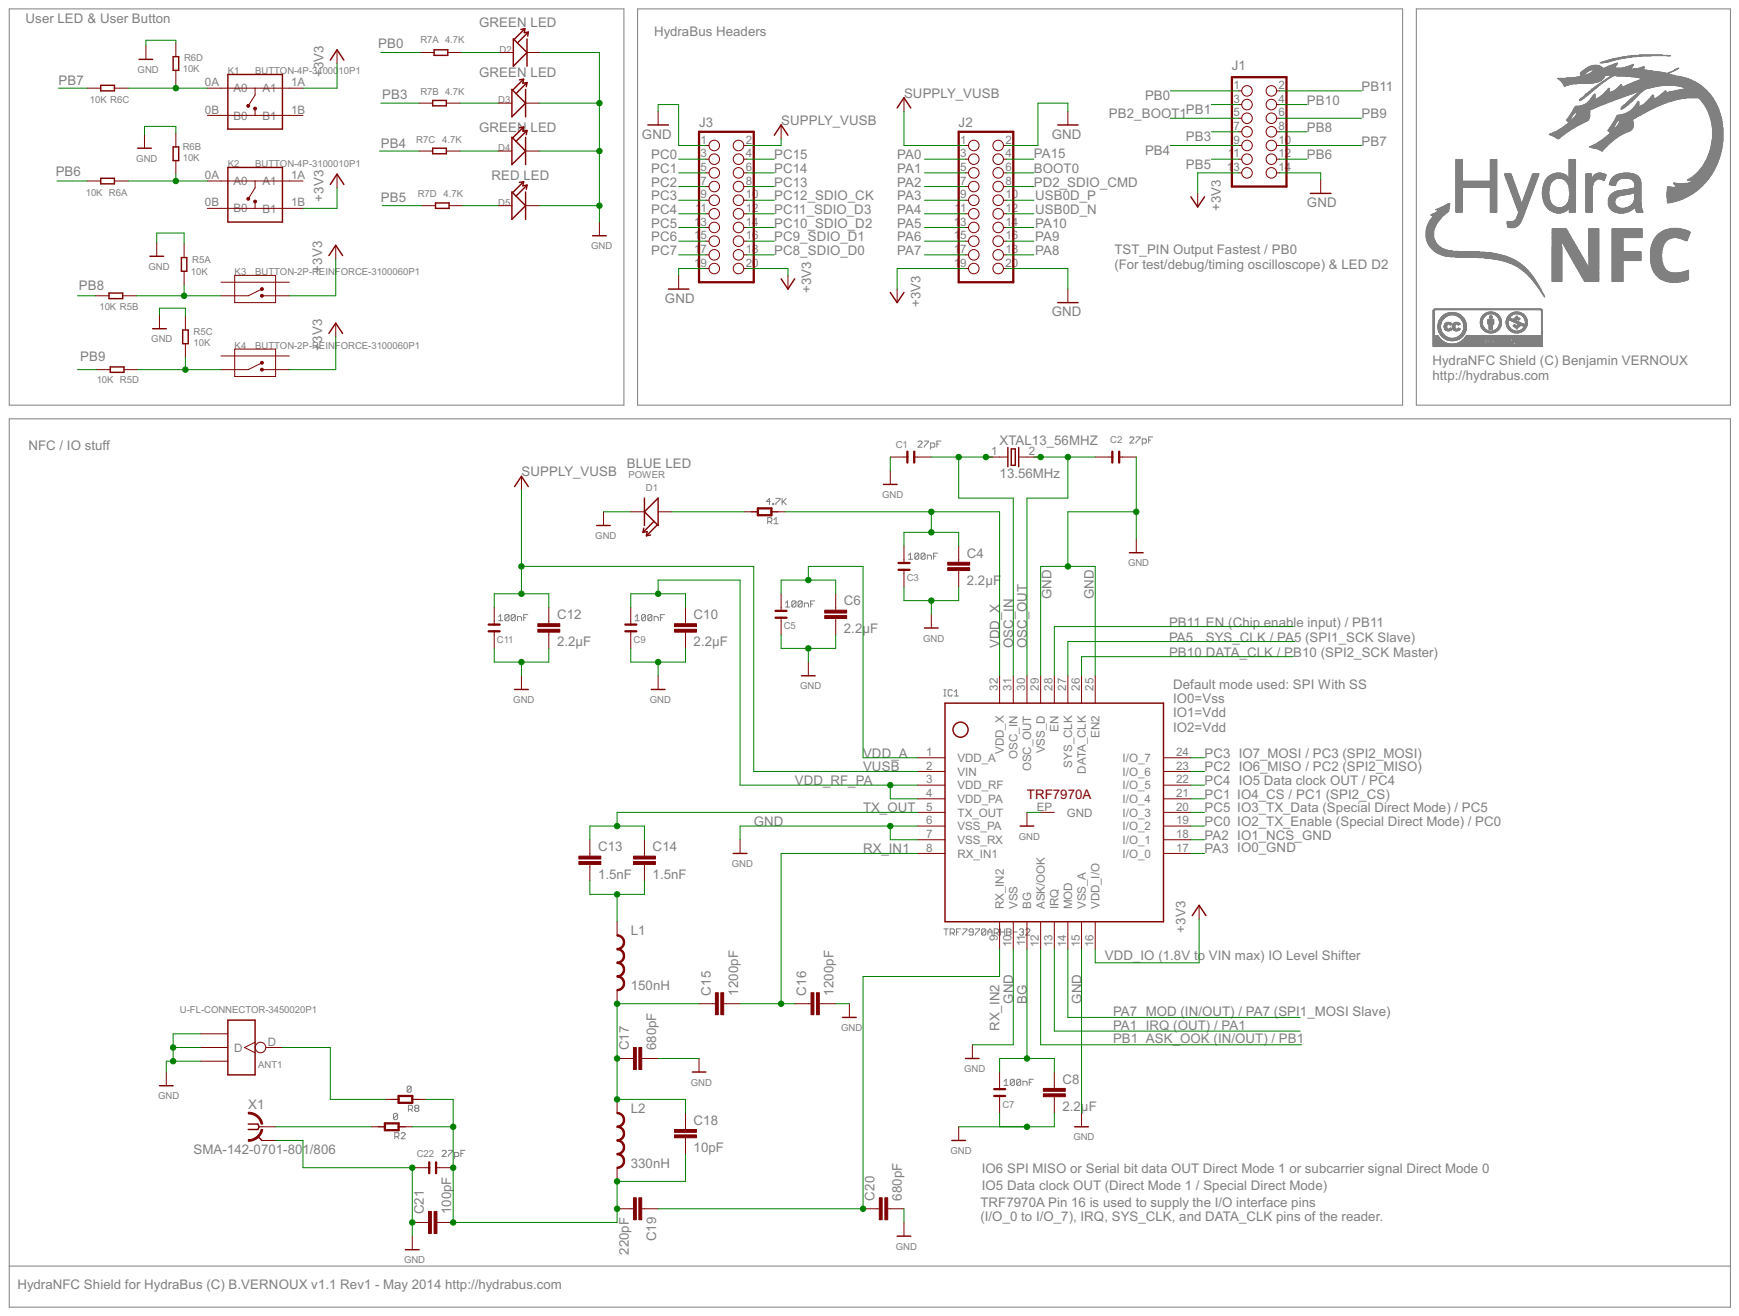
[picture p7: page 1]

User LED & User Button

GREEN LED

TST_PIN Output Fastest / PB0
(For test/debug/timing oscilloscope) & LED D2

BUTTON-2P-REINFORCE-3100060P1

HydraNFC Shield (C) Benjamin VERNOUX
http://hydrabus.com

GND GND

EN (Chip enable input) / PB11
DATA_CLK / PB10 (SPI2_SCK Master) SYS_CLK / PA5 (SPI1_SCK Slave)

Default mode used: SPI With SS
IO0=Vss
IO1=Vdd
IO2=Vdd

VDD_IO (1.8V to VIN max) IO Level Shifter

GND
IO6 SPI MISO or Serial bit data OUT Direct Mode 1 or subcarrier signal Direct Mode 0
IO5 Data clock OUT (Direct Mode 1 / Special Direct Mode)
TRF7970A Pin 16 is used to supply the I/O interface pins
(I/O_0 to I/O_7), IRQ, SYS_CLK, and DATA_CLK pins of the reader.

HydraNFC Shield for HydraBus (C) B.VERNOUX v1.1 Rev1 - May 2014 http://hydrabus.com

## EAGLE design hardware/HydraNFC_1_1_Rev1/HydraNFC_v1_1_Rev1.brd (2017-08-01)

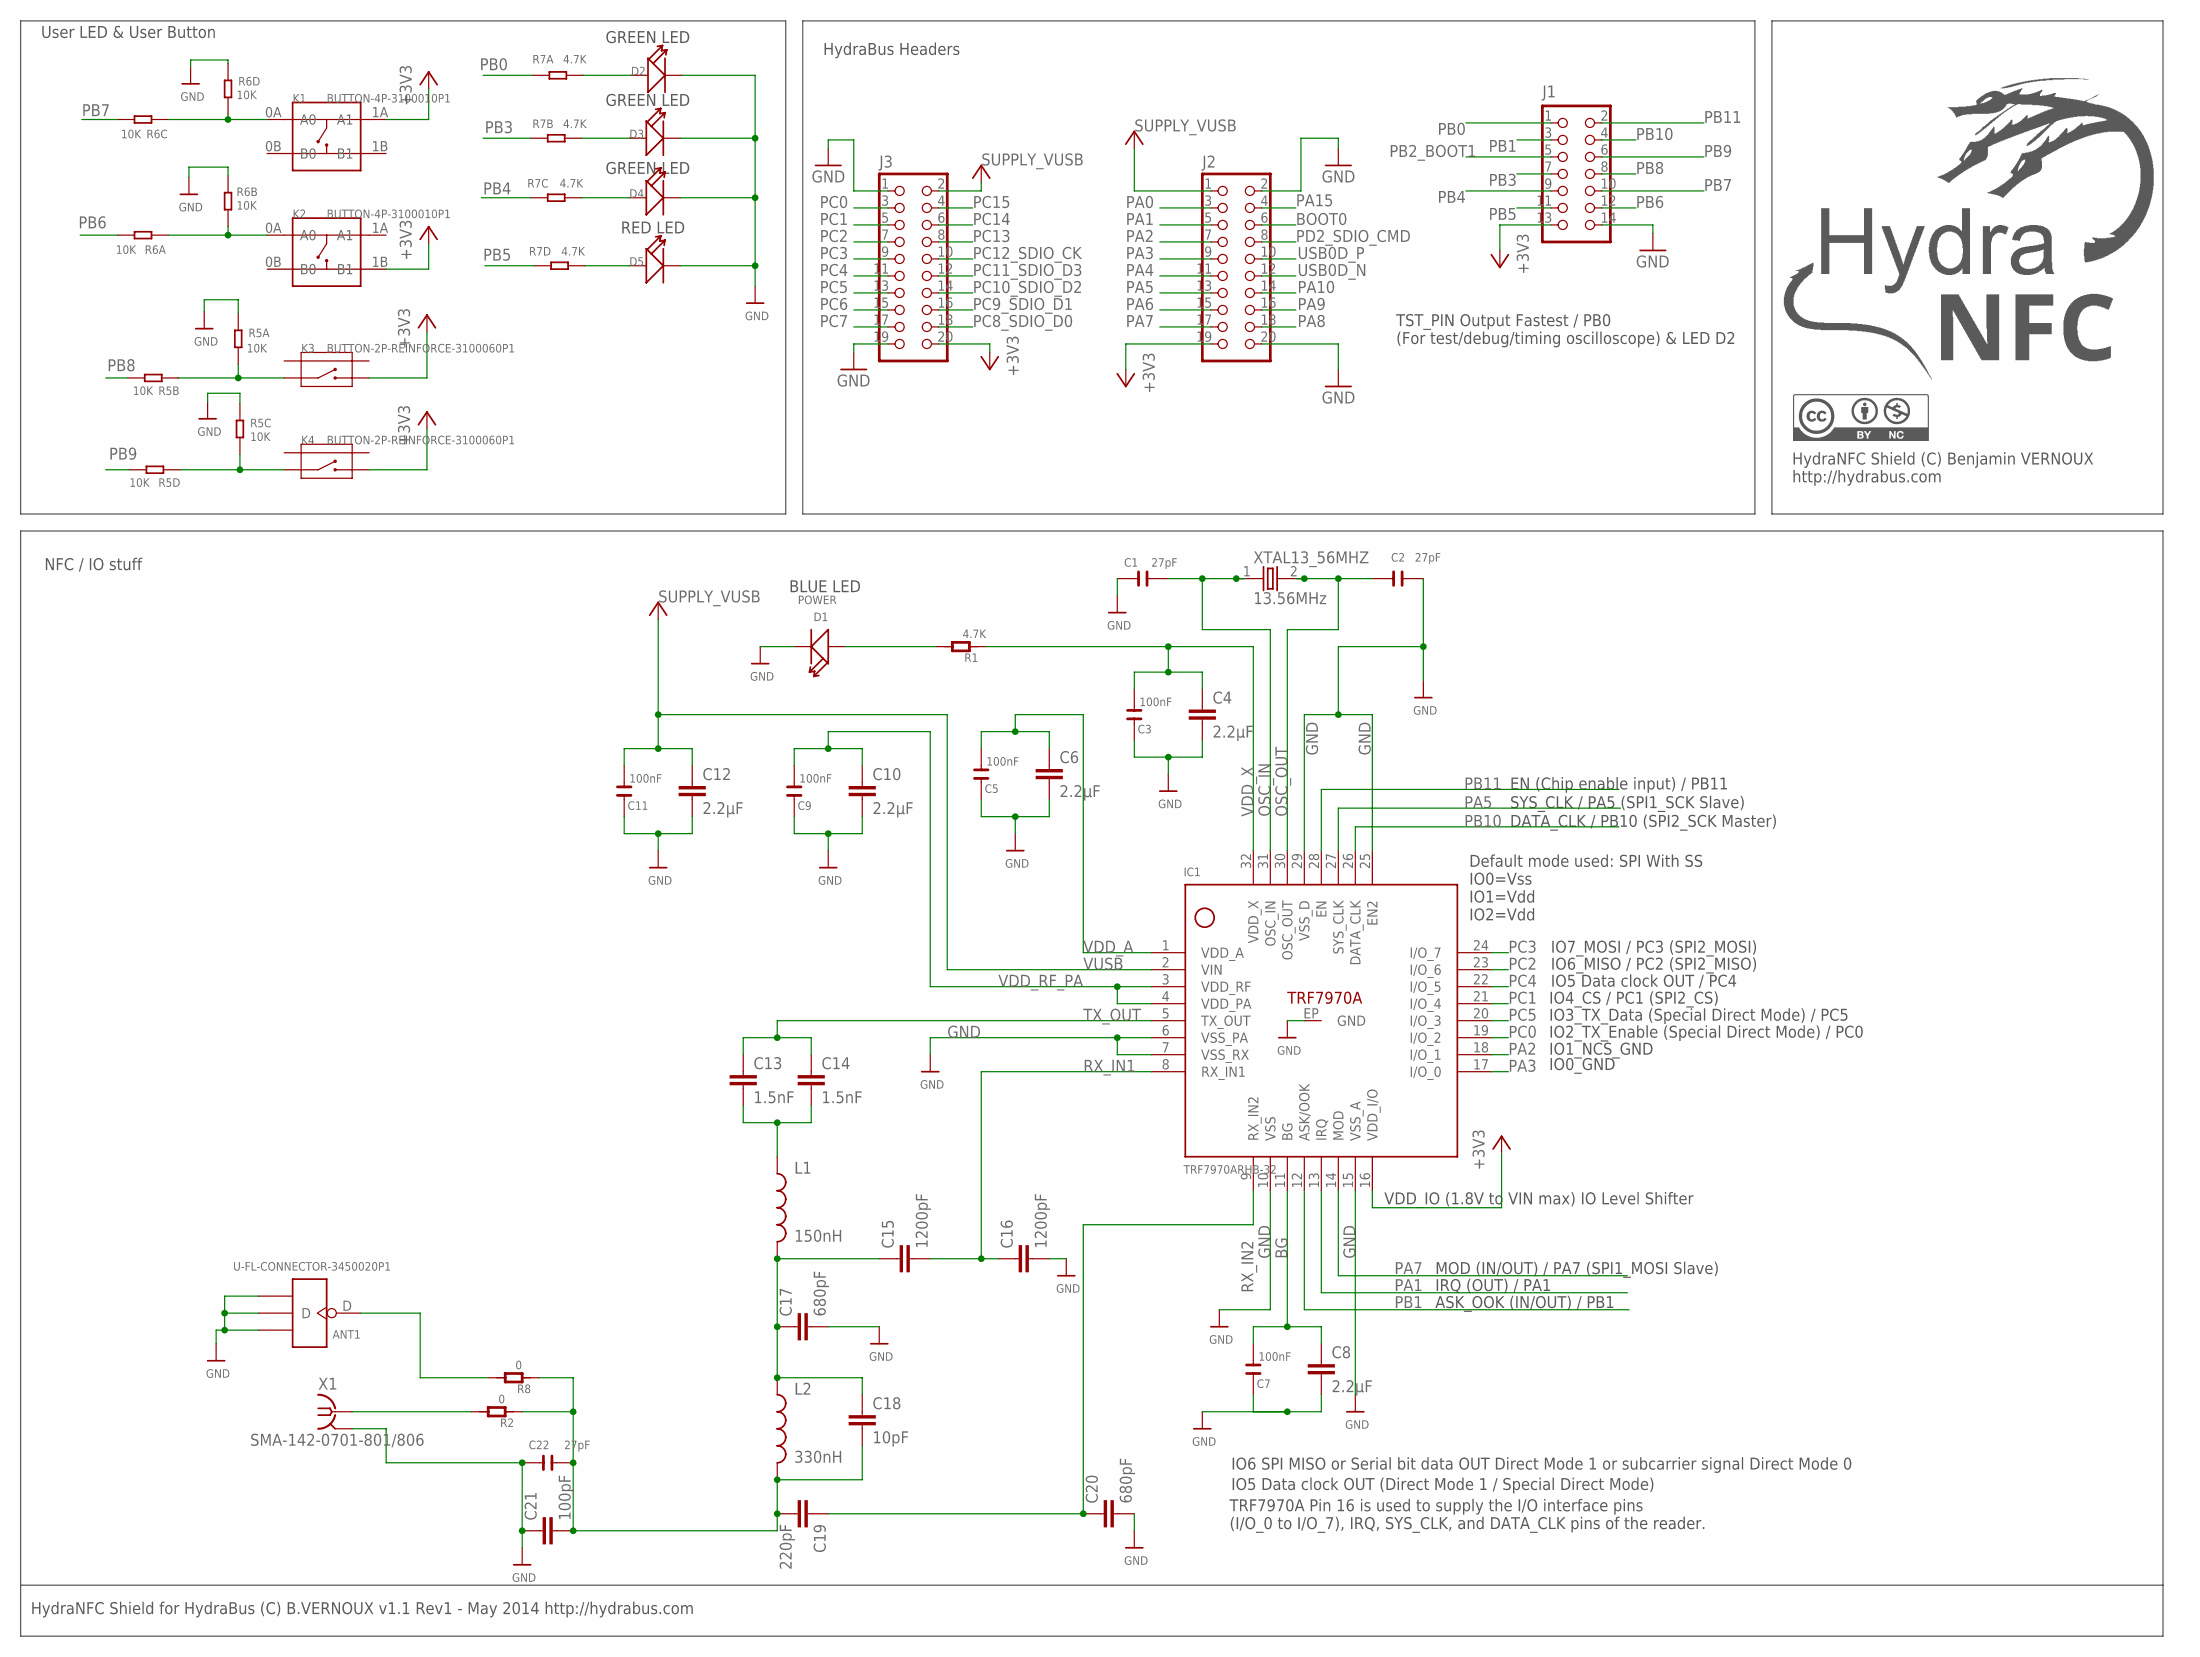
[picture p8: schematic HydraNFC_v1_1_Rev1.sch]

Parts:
ANT1: U-FL-CONNECTOR-3450020P1; U-FL
C1, C2, C22: 27pF; C0603
C3, C5, C7, C9, C11: 100nF; C0603
C4, C6, C8, C10, C12: 2.2µF; C805
C13, C14: 1.5nF; C805
C15, C16: 1200pF; C805
C17, C20: 680pF; C805
C18: 10pF; C805
C19: 220pF; C805
C21: 100pF; C805
D1: POWER; LED0603
D2, D3, D4, D5: LED; LED0603
IC1: TRF7970ARHB-32; TRF7970A
J1: HYDRABUS_SHIELD_CON_HEADER_2X07; HYDRABUS_SHIELD_M2X7
J2, J3: HYDRABUS_SHIELD_CON_HEADER_2X10; HYDRABUS_SHIELD_M2X10
K1, K2: BUTTON-4P-3100010P1; 4P-SMD-6.0X6.0X5.0H
K3, K4: BUTTON-2P-REINFORCE-3100060P1; 4P-SMD-7.0X3.5X3.5H-90D
L1: 150nH; 1210
L2: 330nH; 1210
R1: 4.7K; R0603
R2, R8: 0; R0603
R5, R6: 10K; R1206-8
R7: 4.7K; R1206-8
X1: SMA-142-0701-801/806; J502-ND-142-0701-801/806
XTAL13_56MHZ: 13.56MHz; HC-49U

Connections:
+3V3: IC1.16 (VDD_I/O), J1.13, J2.19, J3.20, K1.1A (A1), K2.1B (B1), K3.2, K4.2
BG: C7.2, C8.1, IC1.11 (BG)
BOOT0: J2.6
GND: ANT1.GND1, ANT1.GND2, ANT1.GND3, C1.1, C2.2, C3.1, C4.2, C5.1, C6.2, C7.1, C8.2, C9.1, C10.2, C11.1, C12.2, C16.2, C17.2, C20.2, C21.1, C22.2, D1.-, D2.-, D3.-, D4.-, D5.-, IC1.6 (VSS_PA), IC1.7 (VSS_RX), IC1.10 (VSS), IC1.15 (VSS_A), IC1.25 (EN2), IC1.29 (VSS_D), IC1.EP (GND), J1.14, J2.2, J2.20, J3.1, J3.19, R5.3 (1), R5.8 (2), R6.4 (1), R6.7 (2), X1.G@1 (GND), X1.G@2 (GND), X1.G@3 (GND), X1.G@4 (GND)
unnamed: C13.2, C14.2, L1.1
unnamed: C18.2, C19.2, C21.2, C22.1, L2.2, R2.2, R8.2
unnamed: C15.1, C17.1, C18.1, L1.2, L2.1
unnamed: D1.+, R1.1
unnamed: R2.1, X1.1
unnamed: K3.1, R5.1, R5.2 (1)
unnamed: K2.0A (A0), R6.2 (1), R6.8 (2)
unnamed: K4.1, R5.5 (2), R5.6 (2)
unnamed: K1.0A (A0), R6.3 (1), R6.5 (2)
unnamed: D2.+, R7.8 (2)
unnamed: D3.+, R7.7 (2)
unnamed: D4.+, R7.6 (2)
unnamed: D5.+, R7.5 (2)
unnamed: ANT1.D, R8.1
OSC_IN: C1.2, IC1.31 (OSC_IN), XTAL13_56MHZ.1
OSC_OUT: C2.1, IC1.30 (OSC_OUT), XTAL13_56MHZ.2
PA0: J2.3
PA1: IC1.13 (IRQ), J2.5
PA2: IC1.18 (I/O_1), J2.7
PA3: IC1.17 (I/O_0), J2.9
PA4: J2.11
PA5: IC1.27 (SYS_CLK), J2.13
PA6: J2.15
PA7: IC1.14 (MOD), J2.17
PA8: J2.18
PA9: J2.16
PA10: J2.14
PA15: J2.4
PB0: J1.1, R7.1
PB1: IC1.12 (ASK/OOK), J1.3
PB2_BOOT1: J1.5
PB3: J1.7, R7.2 (1)
PB4: J1.9, R7.3 (1)
PB5: J1.11, R7.4 (1)
PB6: J1.12, R6.1
PB7: J1.10, R6.6 (2)
PB8: J1.8, R5.7 (2)
PB9: J1.6, R5.4 (1)
PB10: IC1.26 (DATA_CLK), J1.4
PB11: IC1.28 (EN), J1.2
PC0: IC1.19 (I/O_2), J3.3
PC1: IC1.21 (I/O_4), J3.5
PC2: IC1.23 (I/O_6), J3.7
PC3: IC1.24 (I/O_7), J3.9
PC4: IC1.22 (I/O_5), J3.11
PC5: IC1.20 (I/O_3), J3.13
PC6: J3.15
PC7: J3.17
PC8_SDIO_D0: J3.18
PC9_SDIO_D1: J3.16
PC10_SDIO_D2: J3.14
PC11_SDIO_D3: J3.12
PC12_SDIO_CK: J3.10
PC13: J3.8
PC14: J3.6
PC15: J3.4
PD2_SDIO_CMD: J2.8
RX_IN1: C15.2, C16.1, IC1.8 (RX_IN1)
RX_IN2: C19.1, C20.1, IC1.9 (RX_IN2)
TX_OUT: C13.1, C14.1, IC1.5 (TX_OUT)
USB0D_N: J2.12
USB0D_P: J2.10
VDD_A: C5.2, C6.1, IC1.1 (VDD_A)
VDD_RF_PA: C9.2, C10.1, IC1.3 (VDD_RF), IC1.4 (VDD_PA)
VDD_X: C3.2, C4.1, IC1.32 (VDD_X), R1.2
VUSB: C11.2, C12.1, IC1.2 (VIN), J2.1, J3.2

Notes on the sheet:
HydraBus Headers
NFC / IO stuff
HydraNFC Shield for HydraBus (C) B.VERNOUX v1.1 Rev1 - May 2014 http://hydrabus.com
User LED & User Button
Default mode used: SPI With SS IO0=Vss IO1=Vdd IO2=Vdd
IO4_CS / PC1 (SPI2_CS)
IO6_MISO / PC2 (SPI2_MISO)
IO7_MOSI / PC3 (SPI2_MOSI)
IO5 Data clock OUT / PC4
IO3_TX_Data (Special Direct Mode) / PC5
IO1_NCS_GND
IO0_GND
IO2_TX_Enable (Special Direct Mode) / PC0
MOD (IN/OUT) / PA7 (SPI1_MOSI Slave)
DATA_CLK / PB10 (SPI2_SCK Master)
SYS_CLK / PA5 (SPI1_SCK Slave)
IRQ (OUT) / PA1
ASK_OOK (IN/OUT) / PB1
VDD_IO (1.8V to VIN max) IO Level Shifter
IO6 SPI MISO or Serial bit data OUT Direct Mode 1 or subcarrier signal Direct Mode 0
IO5 Data clock OUT (Direct Mode 1 / Special Direct Mode)
EN (Chip enable input) / PB11
TST_PIN Output Fastest / PB0 (For test/debug/timing oscilloscope) & LED D2
TRF7970A Pin 16 is used to supply the I/O interface pins (I/O_0 to I/O_7), IRQ, SYS_CLK, and DATA_CLK pins of the reader.
RED LED
GREEN LED
BLUE LED
HydraNFC Shield (C) Benjamin VERNOUX http://hydrabus.com

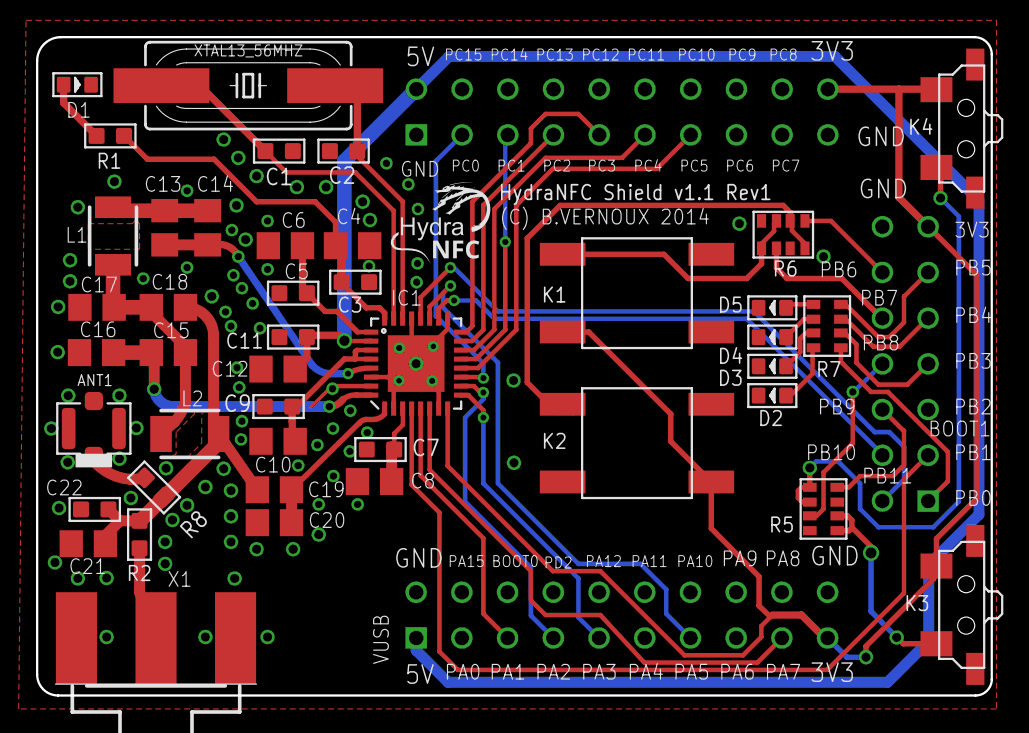
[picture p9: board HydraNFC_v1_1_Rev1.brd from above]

Board: 2 copper layers, 53.0 x 36.6 mm, 46 parts (0 on the bottom side), 48 nets.

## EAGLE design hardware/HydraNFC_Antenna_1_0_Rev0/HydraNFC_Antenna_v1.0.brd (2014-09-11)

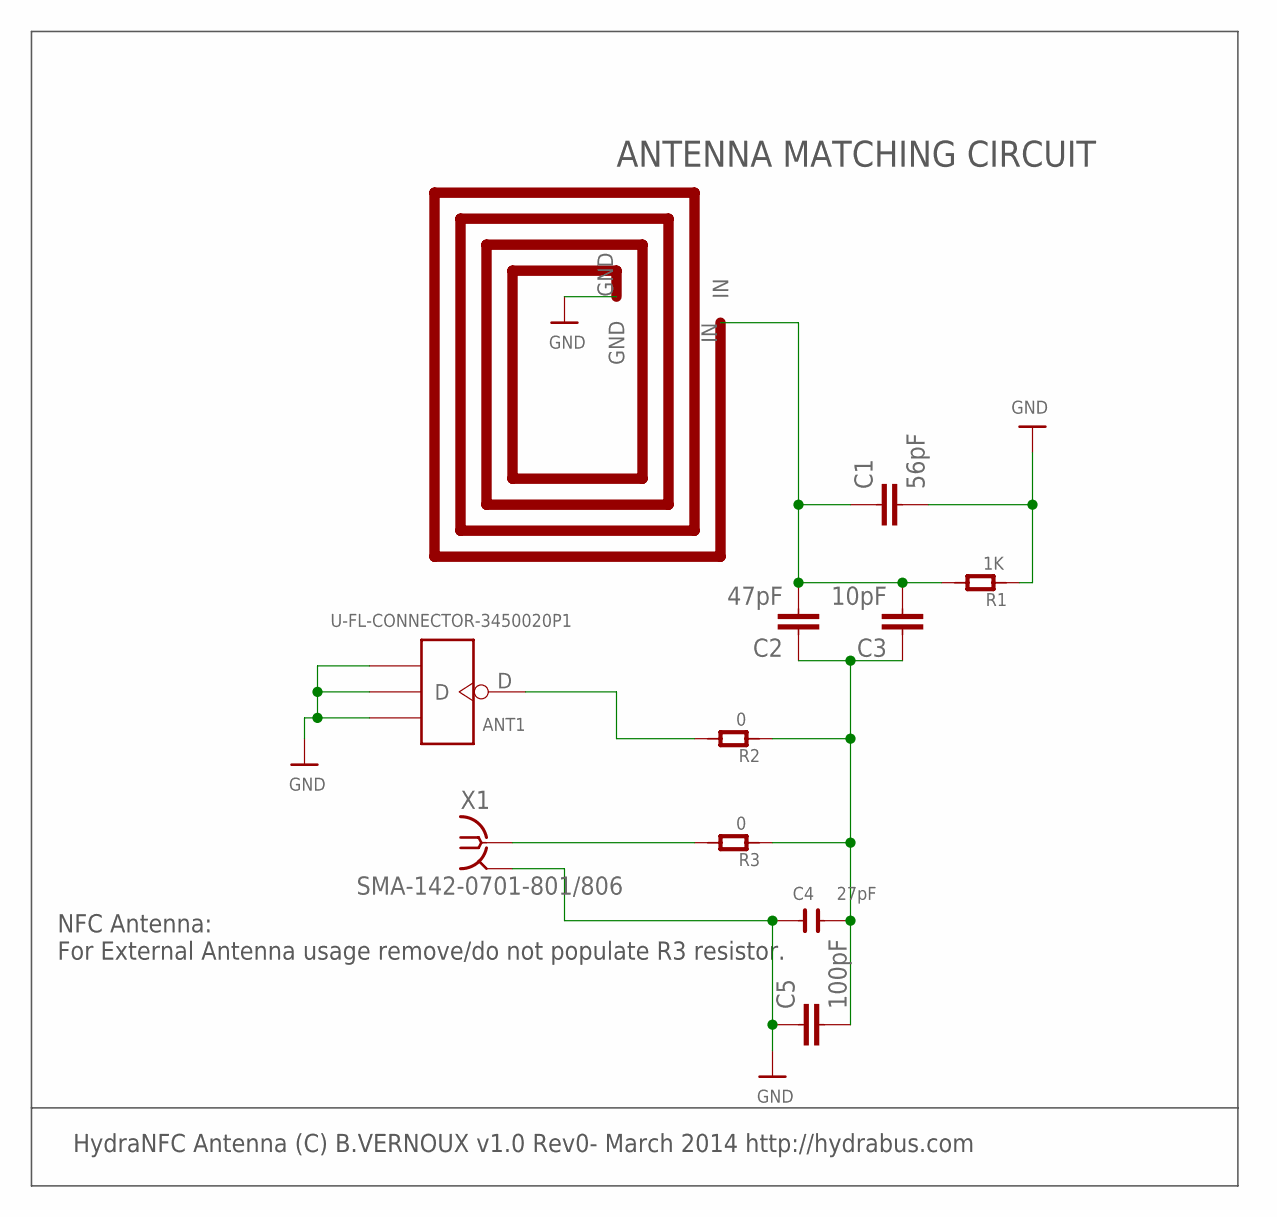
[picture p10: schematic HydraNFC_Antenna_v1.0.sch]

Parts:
ANT1: U-FL-CONNECTOR-3450020P1; U-FL
C1: 56pF; C805
C2: 47pF; C805
C3: 10pF; C805
C4: 27pF; C0603
C5: 100pF; C805
R1: 1K; R0603
R2, R3: 0; R0603
U$43: NFC_13_56MHz_ANTENNA; TRF7970A_ANTENNA
X1: SMA-142-0701-801/806; J502-ND-142-0701-801/806

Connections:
GND: ANT1.GND1, ANT1.GND2, ANT1.GND3, C1.2, C4.2, C5.1, R1.2, U$43.GND, X1.G@1 (GND), X1.G@2 (GND), X1.G@3 (GND), X1.G@4 (GND)
unnamed: C2.1, C3.1, C4.1, C5.2, R2.2, R3.2
unnamed: C1.1, C2.2, C3.2, R1.1, U$43.IN
unnamed: R3.1, X1.1
unnamed: ANT1.D, R2.1

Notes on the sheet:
HydraNFC Antenna (C) B.VERNOUX v1.0 Rev0- March 2014 http://hydrabus.com
ANTENNA MATCHING CIRCUIT
NFC Antenna: For External Antenna usage remove/do not populate R3 resistor.

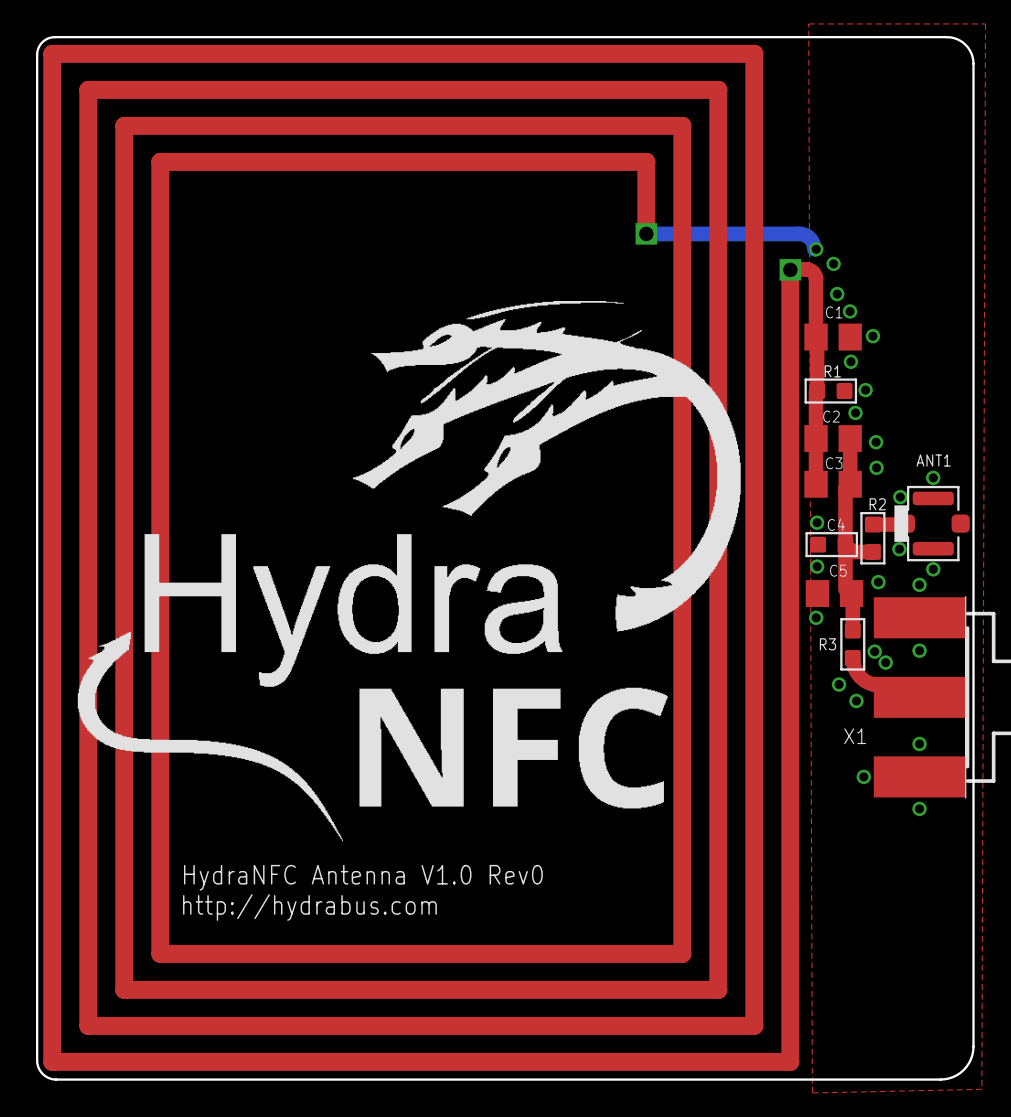
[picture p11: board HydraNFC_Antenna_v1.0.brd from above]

Board: 2 copper layers, 52.0 x 57.9 mm, 11 parts (0 on the bottom side), 5 nets.

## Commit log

2014-07-20 HydraNFC Board
2014-07-24 HydraNFC Hardware Pins and Modes and PinOut
    [HydraNFC_HydraBus_pins.ods]
2014-08-08 Update board photo
2014-09-11 HydraNFC hardware files Eagle, PDF, xls ...
    [HydraNFC_Antenna_v1.0.brd, HydraNFC_Antenna_v1.0.sch, HydraNFC_v1_1_Rev1.brd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]
2016-05-25 Add HydraNFC_LogicAnalyzer documents (LibreOffice ODS & PDF)
    [HydraNFC_LogicAnalyzer.ods]
2017-08-01 Fixed Typo in Schematic/BOM Description for Decoupling Capacitor C3 & C5 & C7 & C9 & C11 which are 100nF (wrong value was 0.01uF so 10nF)
    [HydraNFC_v1_1_Rev1.brd, HydraNFC_v1_1_Rev1.sch, HydraNFC_v1_1_Rev1_BOM.ods]
